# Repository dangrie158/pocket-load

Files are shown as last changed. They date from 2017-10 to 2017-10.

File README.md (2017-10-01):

# Pocket Load

A small electronic dummy load for up to 40V / 6A. 
Further details are added as development progresses;

# Current Status

- Schematic: done
- Board: basically done (waiting for components to verify footprints)
- Firmware: in development (Libraries for Display, ADC, and some smaller interface components done)
- Prototype: board layout will be sent to fab as soon as components arrive
- Specification: Power dissipation ability and accuracy  will be testet as soon as prototype is ready
- Documentation: will be created during development

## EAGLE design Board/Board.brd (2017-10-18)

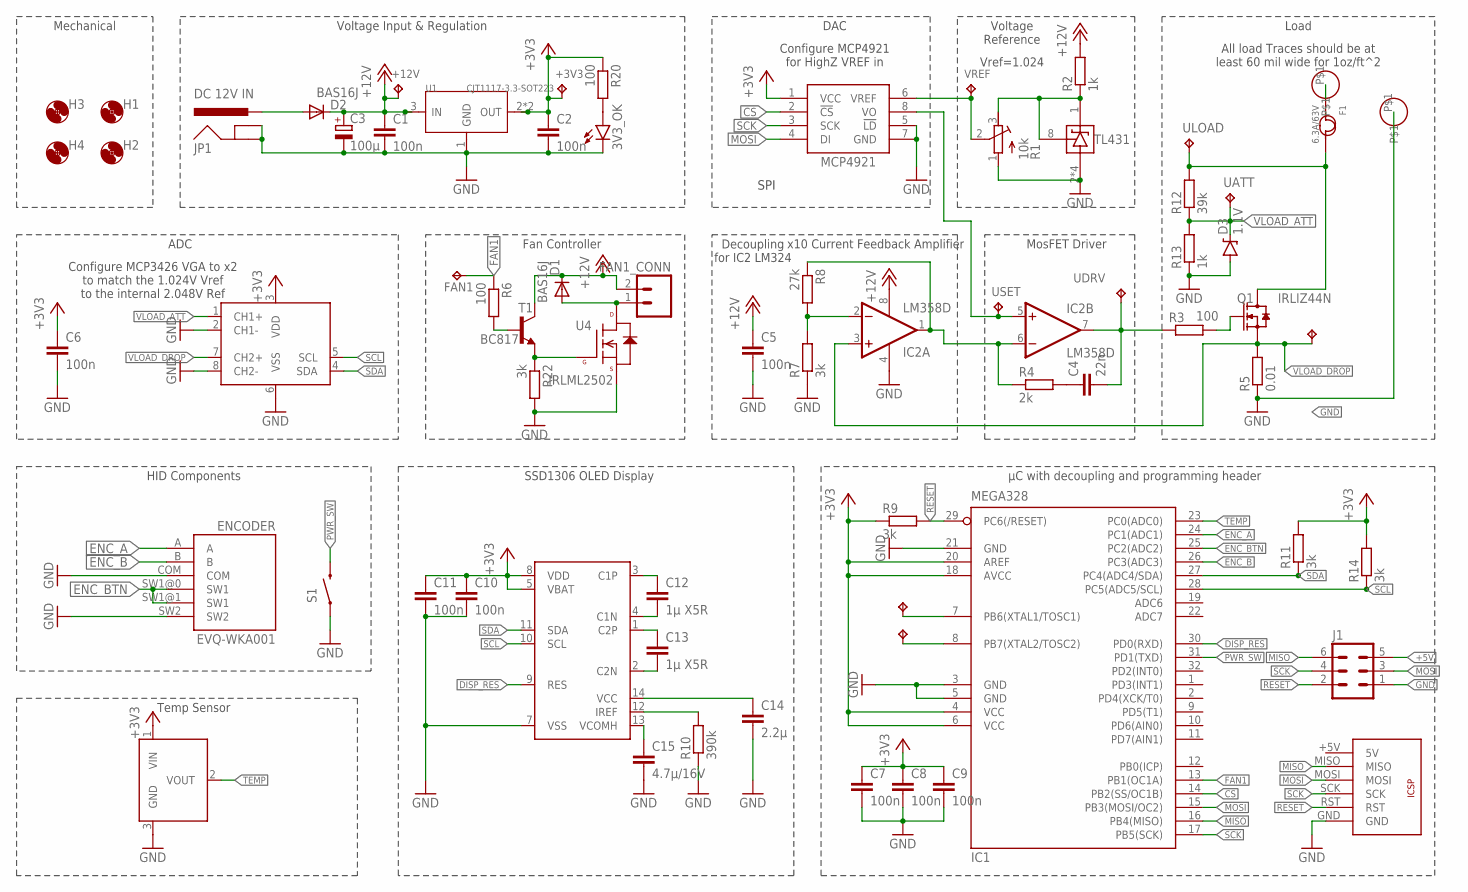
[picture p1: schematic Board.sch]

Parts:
3V3_OK: LED0603; LED-0603
+3V3, +12V: TPB1,27; B1,27
C1, C2, C5, C6, C7, C8, C9, C10, C11: 100n; C0603
C3: 100µ; 153CLV-0405
C4: 22n; C0603
C12, C13: 1µ X5R; C0603
C14: 2.2µ; C0603
C15: 4.7µ/16V; C0603
D1, D2: BAS16J; SOD323-W
D3: 1.1V; SOD-323
ENCODER: EVQ-WKA001
F1: 6.3A/63V; F1206
FAN1: TPB1,27; B1,27
FAN1_CONN: M02POLAR; MOLEX-1X2
H1, H2, H3, H4: MOUNT-HOLE3.0; 3,0
IC1: MEGA328; TQFP32-08
IC2: LM358D; SO08
IC4: MCP3426; SO08
IC6: MCP4921; SO-8
IC7: TL431CD; SO-8
IN+: 6MM-BANANA-MOUNTINGHOLE; 6MM-BANANA-MOUNT
IN-: 6MM-BANANA-MOUNTINGHOLE; 6MM-BANANA-MOUNT
J1: MA03-2
JP1: DC 12V IN; POWER_JACK_PTH
Q1: IRLIZ44N; TO-220H
R1: 10k; RTRIM3296W
R2, R13: 1k; R0603
R3, R6, R20: 100; R0603
R4: 2k; R0603
R5: 0.01; R2512
R7, R9, R11, R14, R22: 3k; R0603
R8: 27k; R0603
R10: 390k; R0603
R12: 39k; R0603
S1: SWITCH-MOMENTARY-2SMD-1101NE; TACTILE-SWITCH-1101NE
T1: BC817; SOT23-BEC
U1: CJT1117-3.3-SOT223; SOT-223
U3: MCP9701AT-E/TT; SOT32-3
U4: IRLML2502; SOT23-3
U$2: 0.86"-OLEDBENT; 0.86"-OLED-BENT
U$4: ICSP; ICSP-SMD-NOSILK
UATT: TPB1,27; B1,27
UDROP: TPB1,27; B1,27
UDRV: TPB1,27; B1,27
ULOAD: TPB1,27; B1,27
USET: TPB1,27; B1,27
VREF: TPB1,27; B1,27
XTAL1, XTAL2: TPB1,27; B1,27

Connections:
+3V3: +3V3.TP, C2.1, C6.1, C7.1, C8.1, C9.1, C10.1, C11.1, IC1.4 (VCC), IC1.6 (VCC), IC1.18 (AVCC), IC1.20 (AREF), IC4.3 (VDD), IC6.1 (VCC), R9.1, R11.2, R14.2, R20.1, U1.2 (OUT), U1.TER (OUT), U3.1 (VIN), U$2.5 (VBAT), U$2.8 (VDD)
+5V: J1.5
+12V: +12V.TP, C1.1, C3.+, C5.1, D1.C, D2.C, FAN1_CONN.2, IC2.8 (V+), R2.2, T1.C, U1.3 (IN)
CS: IC1.14 (PB2(SS/OC1B)), IC6.2 (!CS!)
DISP_RES: IC1.30 (PD0(RXD)), U$2.9 (RES)
ENC_A: ENCODER.A, IC1.24 (PC1(ADC1))
ENC_B: ENCODER.B, IC1.26 (PC3(ADC3))
ENC_BTN: ENCODER.SW1@0 (SW1), ENCODER.SW1@1 (SW1), IC1.25 (PC2(ADC2))
FAN1: FAN1.TP, IC1.13 (PB1(OC1A)), R6.1
GND: 3V3_OK.C, C1.2, C2.2, C3.-, C5.2, C6.2, C7.2, C8.2, C9.2, C10.2, C11.2, C14.2, C15.2, D3.A, ENCODER.COM, ENCODER.SW2, IC1.3 (GND), IC1.5 (GND), IC1.21 (GND), IC2.4 (V-), IC4.2 (CH1-), IC4.6 (VSS), IC4.8 (CH2-), IC6.5 (!LD!), IC6.7 (GND), IC7.2 (ANODE), IC7.3 (ANODE), IC7.6 (ANODE), IC7.7 (ANODE), IN-.P$1, J1.1, JP1.GND, JP1.GNDBREAK, R1.1 (A), R5.1, R7.1, R10.1, R13.1, R22.2, S1.1, U1.1 (GND), U3.3 (GND), U4.2 (S), U$2.7 (VSS), U$4.GND
LOAD+: F1.2, Q1.P$2 (D), R12.2, ULOAD.TP
MISO: IC1.16 (PB4(MISO)), J1.6, U$4.MISO
MOSI: IC1.15 (PB3(MOSI/OC2)), IC6.4 (DI), J1.3, U$4.MOSI
unnamed: IC7.1 (CATHODE), IC7.8 (REF), R1.3 (E), R2.1
unnamed: IC6.6 (VREF), R1.2 (S), VREF.TP
unnamed: C4.1, R4.2
unnamed: R22.1, T1.E, U4.1 (G)
unnamed: D1.A, FAN1_CONN.1, U4.3 (D)
unnamed: Q1.P$1 (G), R3.2
unnamed: F1.1, IN+.P$1
unnamed: R6.2, T1.B
unnamed: IC2.1 (OUT), IC2.6 (-IN), R4.1, R8.1
unnamed: C4.2, IC2.7 (OUT), R3.1, UDRV.TP
unnamed: IC2.2 (-IN), R7.2, R8.2
unnamed: IC1.8 (PB7(XTAL2/TOSC2)), XTAL2.TP
unnamed: IC1.7 (PB6(XTAL1/TOSC1)), XTAL1.TP
unnamed: C12.1, U$2.3 (C1P)
unnamed: C12.2, U$2.4 (C1N)
unnamed: C13.1, U$2.1 (C2P)
unnamed: C13.2, U$2.2 (C2N)
unnamed: C15.1, U$2.13 (VCOMH)
unnamed: R10.2, U$2.12 (IREF)
unnamed: C14.1, U$2.14 (VCC)
unnamed: 3V3_OK.A, R20.2
PWR_SW: IC1.31 (PD1(TXD)), S1.2
RESET: IC1.29 (PC6(/RESET)), J1.2, R9.2, U$4.RST
SCK: IC1.17 (PB5(SCK)), IC6.3 (SCK), J1.4, U$4.SCK
SCL: IC1.28 (PC5(ADC5/SCL)), IC4.5 (SCL), R14.1, U$2.10 (SCL)
SDA: IC1.27 (PC4(ADC4/SDA)), IC4.4 (SDA), R11.1, U$2.11 (SDA)
TEMP: IC1.23 (PC0(ADC0)), U3.2 (VOUT)
VLOAD_ATT: D3.C, IC4.1 (CH1+), R12.1, R13.2, UATT.TP
VLOAD_DROP: IC2.3 (+IN), IC4.7 (CH2+), Q1.P$3 (S), R5.2, UDROP.TP
VLOAD_REF: IC2.5 (+IN), IC6.8 (VO), USET.TP
VSW: D2.A, JP1.PWR

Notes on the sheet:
x10 Current Feedback Amplifier
Decoupling for IC2 LM324
MosFET Driver
Load
Voltage Reference
DAC
Voltage Input & Regulation
Fan Controller
All load Traces should be at least 60 mil wide for 1oz/ft^2
SPI
Configure MCP4921 for HighZ VREF in
ADC
Mechanical
Vref=1.024
Configure MCP3426 VGA to x2 to match the 1.024V Vref to the internal 2.048V Ref
HID Components
Temp Sensor
SSD1306 OLED Display
µC with decoupling and programming header

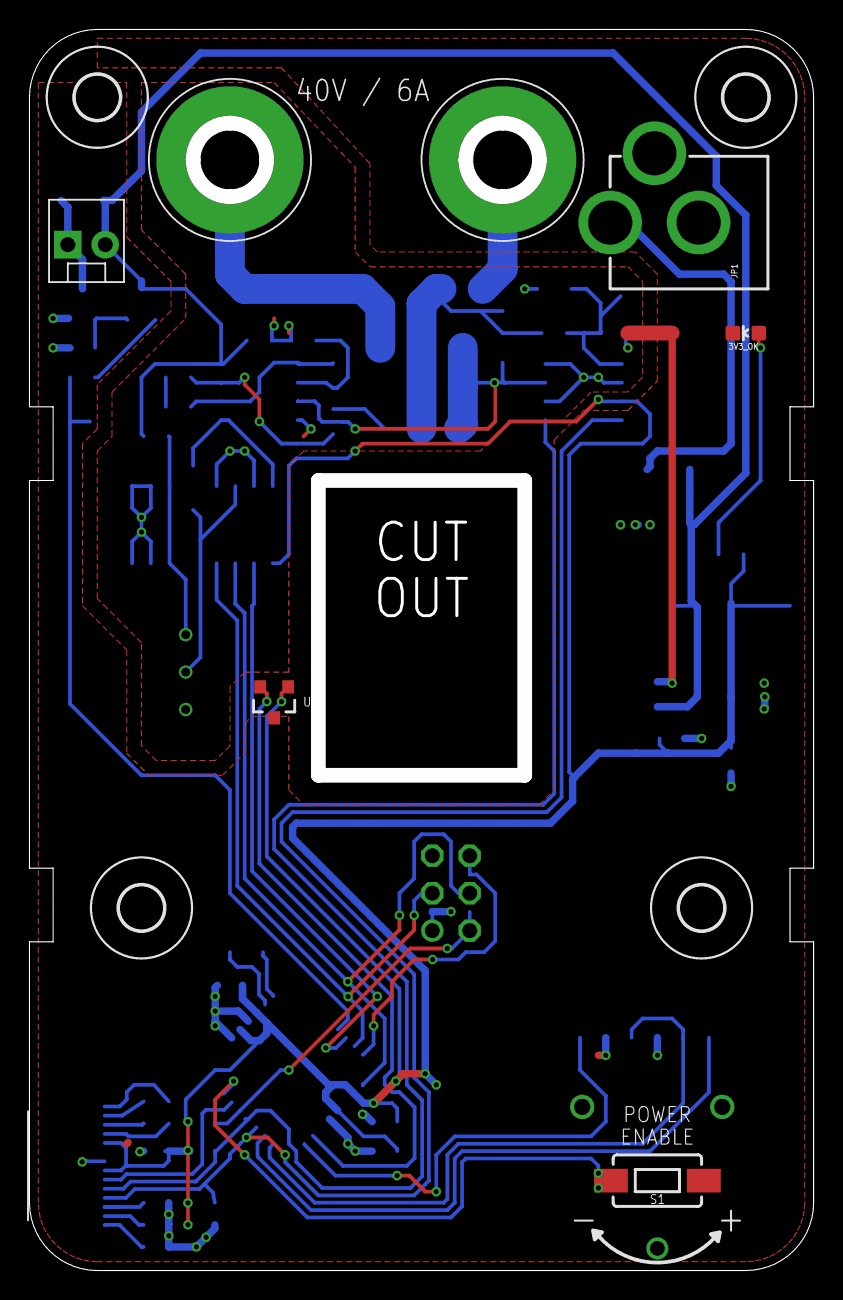
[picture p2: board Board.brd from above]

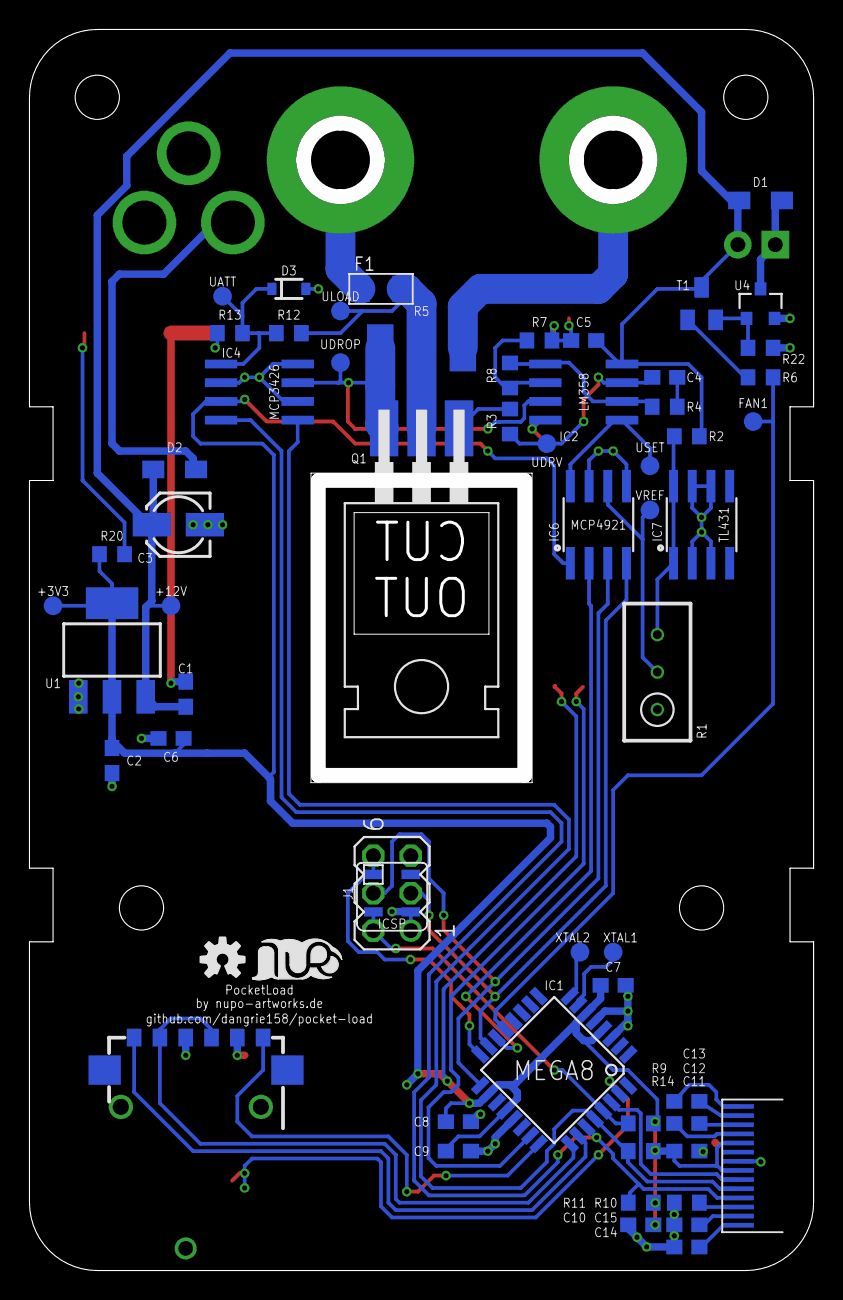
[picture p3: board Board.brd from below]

Board: 2 copper layers, 53.2 x 84.2 mm, 72 parts (60 on the bottom side), 43 nets.

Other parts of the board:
U$1: LOGO-SILKSCREEEN-S
U$3: OSHW-LOGO-S

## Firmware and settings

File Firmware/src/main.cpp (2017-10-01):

#include <Arduino.h>
#include <ClickEncoder.h>
#include <TimerOne.h>

#include "MCP4921.h"
#include "SSD1306.h"
#include "Font5x7.h"
#include "Font11x15.h"
#include "Button.h"
#include "Output.h"
#include "AnalogInput.h"

#include "definitions.h"
#include "bitmaps.h"

SSD1306 display;
Font5x7 smallFont;
Font11x15 bigFont;

MCP4921 dac(MCP4921_CS);

ClickEncoder encoder(ENC_A, ENC_B, ENC_BTN, ENC_STEPS_PER_NOTCH);
Button powerButton(BTN_PWR, true);
Output fan(FAN);
AnalogInput tempSensor(TEMP_SENS, 1.0f, 100);

uint32_t accumulatedmWh = 0; //accumulated milliWattHours
uint32_t accumulatedmAh = 0; //accumulated milliAmpereHours

uint32_t accumulatedmAmsec = 0; //accumulated milliAmpereMilliSeconds
uint32_t accumulatedmWmsec = 0; //accumulated milliWattMilliSeconds

uint16_t currentSet = 0; // current setpoint in mA

//which detail to show
// 0: Ampere
// 1: Watts
// 2: milli Amperehours
// 3: milli Watthours
uint8_t currentDetail = 0;

bool poweredOn = true;
bool loadEnabled = false;

uint8_t dacValueForCurrent(uint16_t current){
  return 0; //TODO:
}

void timerIsr() {
  encoder.service();
  powerButton.update();
}

void resetAccumulatedValues(){
  accumulatedmWh = 0;
  accumulatedmAh = 0;

  accumulatedmAmsec = 0;
  accumulatedmWmsec = 0;
}

void switchOnLoad(){
  dac.setValue(dacValueForCurrent(currentSet));
  loadEnabled = true;
}

void switchOffLoad(){
  dac.setValue(0);
  loadEnabled = false;
}

void powerDown(){
  switchOffLoad();

  display.shutdown();
  dac.shutdown();

  poweredOn = false;
}

void powerUp(){
  display.reset();
  display.drawBitmap(nupoLogo, 16, 0);
  display.refresh();
  delay(1000);
  dac.wakeup();
  resetAccumulatedValues();
  display.clear();

  switchOffLoad();

  //reset to a "save" state
  currentDetail = 0;
  poweredOn = true;
}

void drawCurrent(uint32_t loadCurrent){
  String text = String(loadCurrent / 1000.f, 3) + " A";
  uint8_t textWidth = bigFont.getTextWidth(text);
  uint8_t startX = (OLED_WIDTH - textWidth) / 2;

  display.drawText(text, startX, 0, bigFont);
}

void drawPower(uint32_t loadPower){
  String text = String(loadPower / 1000.0f, 2) + " W";
  uint8_t textWidth = bigFont.getTextWidth(text);
  uint8_t startX = (OLED_WIDTH - textWidth) / 2;

  display.drawText(text, startX, 0, bigFont);
}

void drawmAh(uint32_t accumulatedmAh){
  String text;
  if(accumulatedmAh < 1000){
    text = String(accumulatedmAh) + " mAh";
  }else{
    text = String(accumulatedmAh / 1000.f, 2) + " Ah";
  }

  uint8_t textWidth = bigFont.getTextWidth(text);
  uint8_t startX = (OLED_WIDTH - textWidth) / 2;

  display.drawText(text, startX, 0, bigFont);
}

void drawmWh(uint32_t accumulatedmWh){
  String text;
  if(accumulatedmWh < 10000){
    text = String(accumulatedmWh / 1000.f, 2) + " Wh";
  }else{
    text = String(accumulatedmWh / 1000.f, 1) + " Wh";
  }

  uint8_t textWidth = bigFont.getTextWidth(text);
  uint8_t startX = (OLED_WIDTH - textWidth) / 2;

  display.drawText(text, startX, 0, bigFont);
}

void drawSecondaryInfo(uint32_t setCurrent, uint32_t loadCurrent, uint32_t loadVoltage, uint16_t temperature){
  uint8_t cellWidth = OLED_WIDTH / 3;

  //display the setpoint of the current on the left
  String cell1 = String(setCurrent / 1000.f, 2) + "A";
  display.drawText(cell1, 0, 3, smallFont);
  display.drawProgressbar((loadCurrent * 100) / I_MAX, 0, 2, (OLED_WIDTH / 3) - 1);

  //display the temperature centered on the screen
  String cell2 = String(temperature) + "nC";
  uint8_t startX = cellWidth + ((cellWidth - smallFont.getTextWidth(cell2)) / 2);
  display.drawText(cell2, startX, 3, smallFont);
  display.drawProgressbar((temperature * 100) / T_MAX, OLED_WIDTH / 3 * 1, 2, (OLED_WIDTH / 3) - 1);

  //display the current voltage right-aligned
  String cell3 = String(loadVoltage / 100.f, 2) + "V";
  uint8_t width = smallFont.getTextWidth(cell3);
  display.drawText(cell3, OLED_WIDTH - width, 3, smallFont);
  display.drawProgressbar((loadVoltage * 100) / U_MAX, OLED_WIDTH / 3 * 2, 2, (OLED_WIDTH / 3) - 1);
}

uint16_t measureVoltage(){
  //TODO: implement ADC reading
  static uint16_t base = 3500;
  //base += random(-10, 10);
  return base;
}

uint16_t measureCurrent(){
  //TODO: implement ADC reading
  return loadEnabled ? currentSet : 0;
}

uint8_t measureTemperature(){
  uint16_t voltage = map(tempSensor.read(), 0, 1024, 0, 3300);
  uint8_t temp = (voltage - V0) / Tc;
  return temp;
}

void setCurrent(uint32_t current){
  if(current >= 0 && current <= I_MAX){
    currentSet = current;
    if(loadEnabled){
      dac.setValue(dacValueForCurrent(currentSet));
    }
  }
}

void handleHID() {
  //handle power button
  if(powerButton.getStatus() == Clicked){
    if(!poweredOn){
      powerUp();
    }else{
      if(loadEnabled){
        switchOffLoad();
      }else{
        switchOnLoad();
      }
    }
  }else if(powerButton.getStatus() == Held){
    if(poweredOn){
      powerDown();
    }
  }

  //handle encoder
  if(poweredOn){
    int16_t encoderNewSteps = encoder.getValue();
    setCurrent(currentSet + (encoderNewSteps * 10));
  }

  //handle encoder button
  ClickEncoder::Button buttonState = encoder.getButton();
  switch (buttonState) {
    case ClickEncoder::Held:
      resetAccumulatedValues();
      break;
    case ClickEncoder::Clicked:
      currentDetail = (currentDetail + 1) % 4;
      break;
    default:
      break;
  }
}

void setup()   {
  display.begin();
  powerUp();
  display.clear();

  Timer1.initialize(1000);
  Timer1.attachInterrupt(timerIsr);

  encoder.setAccelerationEnabled(true);
}

void loop() {

  // check the fan temperature outside the poweredOn check
  // to make sure the FET can cool down quickly, even if
  // the user switches it off while its hot
  uint8_t heatsinkTemperature = measureTemperature(); // °C
  if(heatsinkTemperature > FAN_TEMP_HIGH){
    fan.switchOn();
  }else if(heatsinkTemperature < FAN_TEMP_LOW){
    fan.switchOff();
  }

  handleHID();

  if(poweredOn){
    static uint32_t lastUpdate = millis();

    uint32_t loadVoltage = measureVoltage(); // mV
    uint32_t loadCurrent = measureCurrent(); // mA
    uint32_t loadPower = (loadVoltage * loadCurrent) / 100; //mW
    uint32_t timeSinceLastUpdate = millis() - lastUpdate; // mS
    lastUpdate = millis();

    accumulatedmAmsec += loadCurrent * timeSinceLastUpdate;
    if(accumulatedmAmsec >= USEC_PER_HOUR){
      accumulatedmAh += 1;
      accumulatedmAmsec -= USEC_PER_HOUR;
    }

    accumulatedmWmsec += loadPower * timeSinceLastUpdate;
    if(accumulatedmWmsec >= USEC_PER_HOUR){
      accumulatedmWh += 1;
      accumulatedmWmsec -= USEC_PER_HOUR;
    }

    display.clear();

    //draw primary info
    switch(currentDetail){
      case 0:
        drawCurrent(loadCurrent);
        break;
      case 1:
        drawPower(loadPower);
        break;
      case 2:
        drawmAh(accumulatedmAh);
        break;
      case 3:
        drawmWh(accumulatedmWh);
        break;
    }
    drawSecondaryInfo(currentSet, loadCurrent, loadVoltage, heatsinkTemperature);

    display.refresh();
  }
}

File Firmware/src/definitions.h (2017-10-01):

#include <Arduino.h>

#define MCP4921_CS 10
#define ENC_A A1
#define ENC_B A3
#define ENC_BTN A2
#define BTN_PWR 1
#define FAN 9
#define TEMP_SENS A0

#define ENC_STEPS_PER_NOTCH 4

//software defined limits
#define T_MAX 90   // 90°C
#define I_MAX 6000 // 6A
#define U_MAX 4000 // 40V

#define FAN_TEMP_HIGH 30 //temperature at which the an switches on
#define FAN_TEMP_LOW 27 //temperature at which the an switches off again

//from MCP9701 datasheet
#define Tc 19.5f
#define V0 400

#define USEC_PER_HOUR 1000L * 60L * 60L

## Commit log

2017-10-01 firmware improvements
    [Board.brd, Board.sch]
2017-10-01 added nupo logo to bottom silkscreen
    [Board.brd]
2017-10-01 fixed power on bug
    [main.cpp]
2017-10-02 added OSHW logo
    [Board.brd, Board.sch]
2017-10-03 added link to github repo
    [Board.brd]
2017-10-03 improved thermal performance of temp sensor
    [Board.brd]
2017-10-04 added zener to vload_att net to protect from overvoltage conditions
    [Board.brd, Board.sch]
2017-10-18 added throughhole ICSP header
    [Board.brd, Board.sch]
2017-10-18 added testpads for XTAL1 and XTAL2
    [Board.brd, Board.sch]

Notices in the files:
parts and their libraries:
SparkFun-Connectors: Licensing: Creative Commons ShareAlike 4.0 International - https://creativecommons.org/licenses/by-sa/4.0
